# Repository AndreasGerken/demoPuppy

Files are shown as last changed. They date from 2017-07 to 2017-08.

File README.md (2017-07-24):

# Demo Puppy

This is a fork of the demoPuppy which was originally designed by K. Dermitzakis [dermitza](https://github.com/dermitza). The original files are described on his [website](https://dermitza.github.io/demoPuppy/).

## Modified files
New models were added which are compatible with the original models. They include
- Servo holders for cheap Carson CS-3 standard size servos
- Flexible legs which can be printed in one piece with flexible filament. We used [Ninjatek's Ninjaflex](https://ninjatek.com/products/filaments/ninjaflex/).
- A one piece body unit which has the holes to hold a Arduino Mega
- A holder for the IMU "MPU6050" which fits to the one piece body

All included files can be 3D printed. We used an Ultimaker2.

The new models are included in the [V5 pack](packs/puppy_v05_one_part_stl.zip). This configuration is shown in the following image:

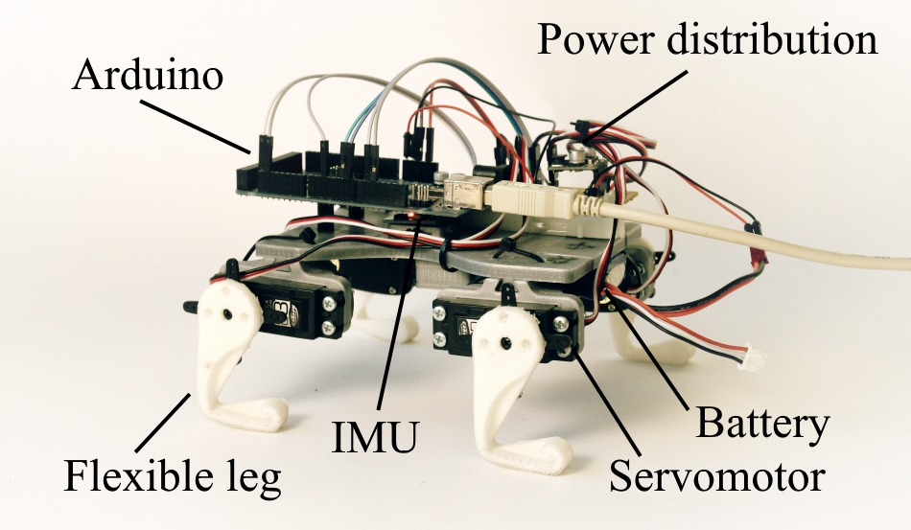
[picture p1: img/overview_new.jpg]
DemoPuppy V5


## Electronics

In our configuration puppy has an IMU and 4 servos for the legs. They can be wired as shown in the following graphic
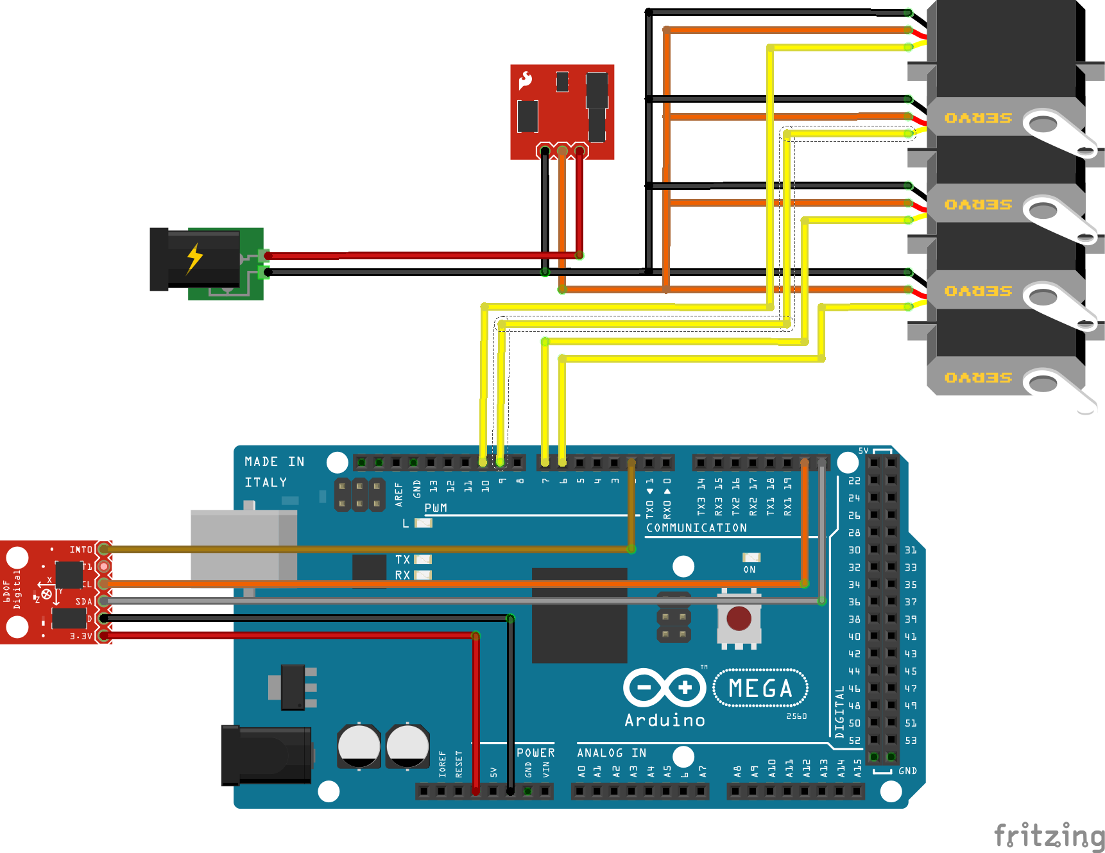
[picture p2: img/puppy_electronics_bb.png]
Wiring


- The red chip on the left is the MPU6050
- the red chip on the top is a voltage regulator. It should fit the requirements of the Servos.
- We use an Arduino Mega

## Arduino program

The arduino program found in arduino/puppy_base is compatible with the wiring shown before.

### Installation
Many parts of the program are identical with the code in the [tinyIMU](https://github.com/AndreasGerken/tinyIMU_arduino) repository.
This repository has a step by step instruction how to install the package which have to be followed to use this package.

### Features
- The program is [ROS](http://www.ros.org/) enabled and can communicate to a ros master via [rosserial](http://wiki.ros.org/rosserial)
- The program reads the IMU measurements with a high frequency (~300Hz), and publishes a smoothed version at around 20Hz with the topic "\tinyIMU" and in the tinyIMU data type to reduce data traffic.
- The program subscribes to motor commands with the topic "\puppyMotor" and gives the corresponding PWM commands to the servos. The value range is between (-32768 and 32768)
- The program runs a diagnostic about the load percentage in it's loop and publishes it with the topic "\timing"

## Additional repositories
 - To transfer the tinyIMU messages to a standard IMU message the package [tinyIMU_relay](https://github.com/superjax/tinyIMU_relay) can be used. The package has a scaling feature to convert the raw values to ROS standard units.
 - The repository [smp_control](https://github.com/AndreasGerken/smp_control) includes configuration files for self exploration of this robot.

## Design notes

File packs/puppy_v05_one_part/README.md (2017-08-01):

# puppy_V05

This version uses the following parts:
- One part body:           With mounting holes for the Arduino Mega
- imu holder:              Holder for the imu MPU 6050
- 4x Servo holder CS-3:    Holders for the Carson CS-3 Servos
- 4x Flexible Legs:        With mounting holes for Carson CS-3 horn

PLA parts
- 0.1 Layer Height
- Support Structure
- PLA (we used Form Futura EasyFillPLA)
- Orient the body to easily remove support
- Aproximately 8.6m Material
- 2 Gradual infill steps (Cura 2.6)
- 750g roll costs 24€ and has 168m ->8.6m = 1,23€
- Shapeways ~75€ incl VAT and shipping
https://rigid.ink/blogs/news/how-many-meters-of-filament-on-a-spool

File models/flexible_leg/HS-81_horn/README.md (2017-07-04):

# Flexible leg for Hitech HS-81 horn

All models in this folder are meant to connect to the horn of the Hitech HS-81 servo. The basic model is the same for V2, V3 and V4 but the parameters are configured.

## Parameter meaning
|Param  |Meaning |
|---|---|
|x |Thight lenght |
|y |Knee thickness |
|z |Lower leg length  |
|alpha  |Knee bend angle |
|a |Foot circle radius|

## Version parameter configurations
|Version|x |y |z |alpha|a  |
|---|----|-----|----|-----|---|
|V2 |35mm|3mm  |25mm|35deg|6mm|
|V3 |38mm|3mm  |23mm|30deg|6mm|
|V4 |35mm|3.5mm|23mm|30deg|6mm|

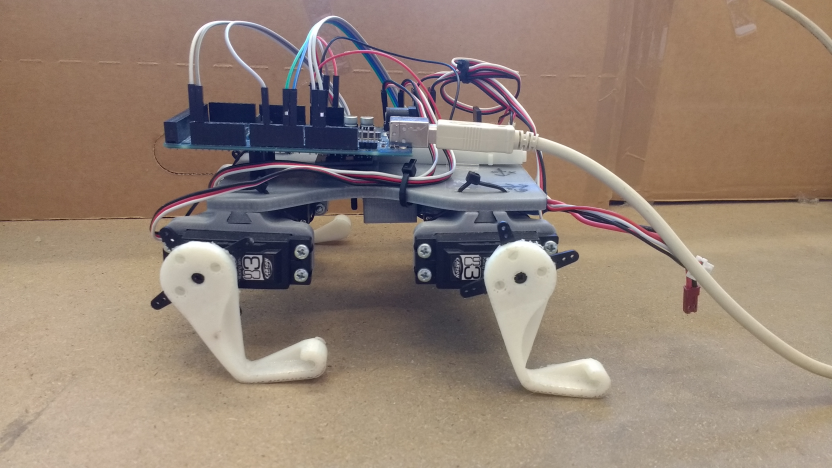
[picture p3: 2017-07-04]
img/demoPuppy_V5.png

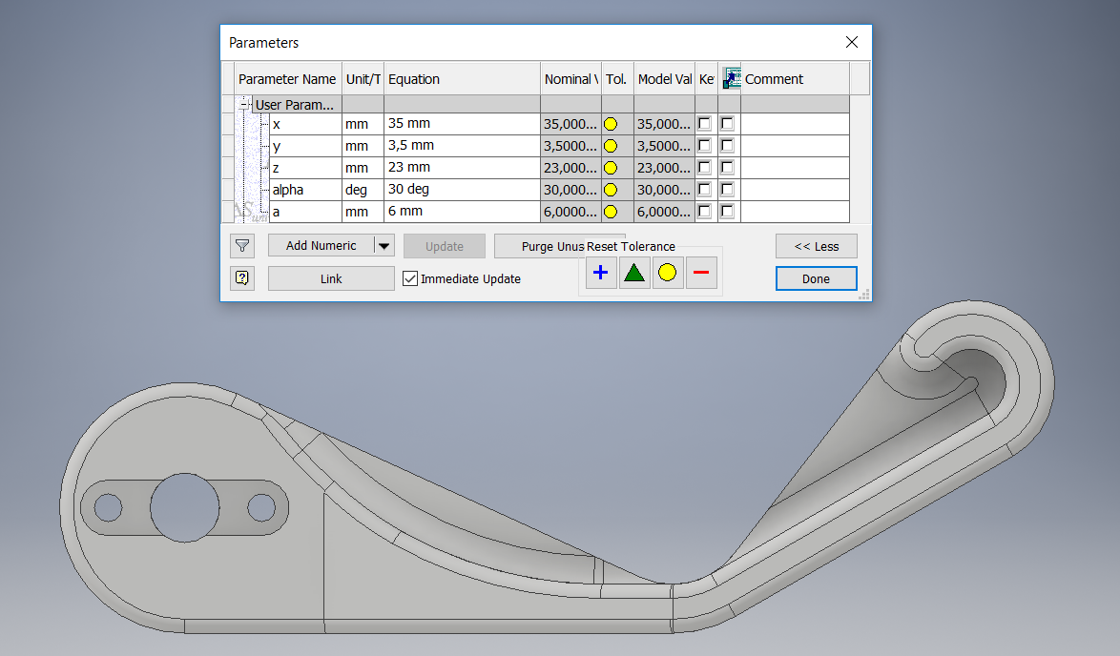
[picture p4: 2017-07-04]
models/flexible_leg/HS-81_horn/V4/flexible_leg_HS-81_V4.PNG

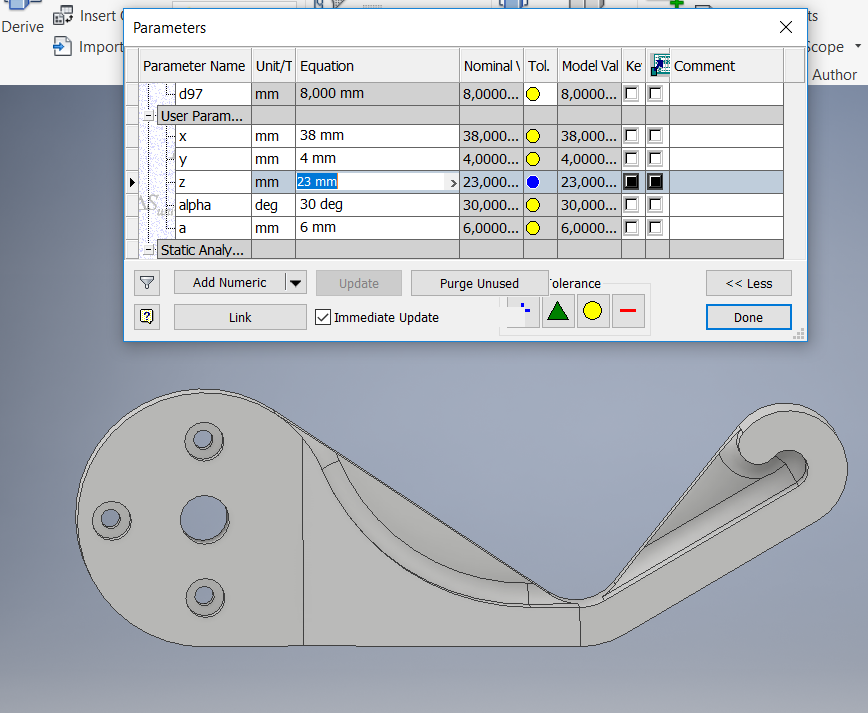
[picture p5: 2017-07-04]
models/flexible_leg/CS-3_horn/flexible_leg_CS-3_V5/flexible_leg_CS-3_V5.PNG

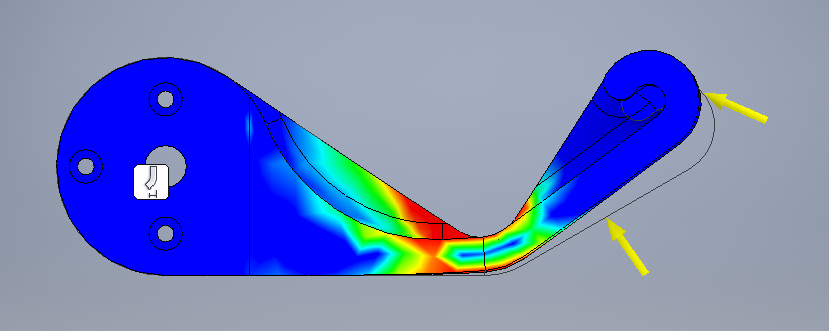
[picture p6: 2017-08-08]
models/flexible_leg/CS-3_horn/flexible_leg_CS-3_V5/flexible_leg_CS-3_V5_stress.png

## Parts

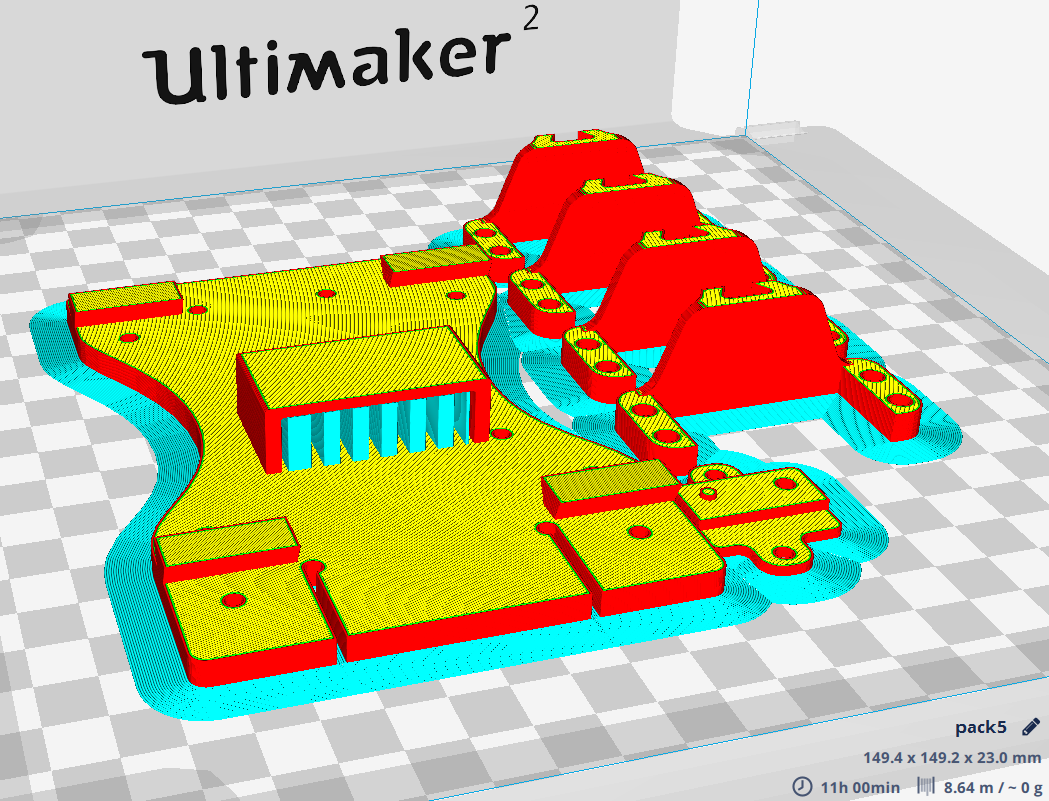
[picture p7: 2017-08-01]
packs/puppy_v05_one_part/cura_pla_parts.PNG

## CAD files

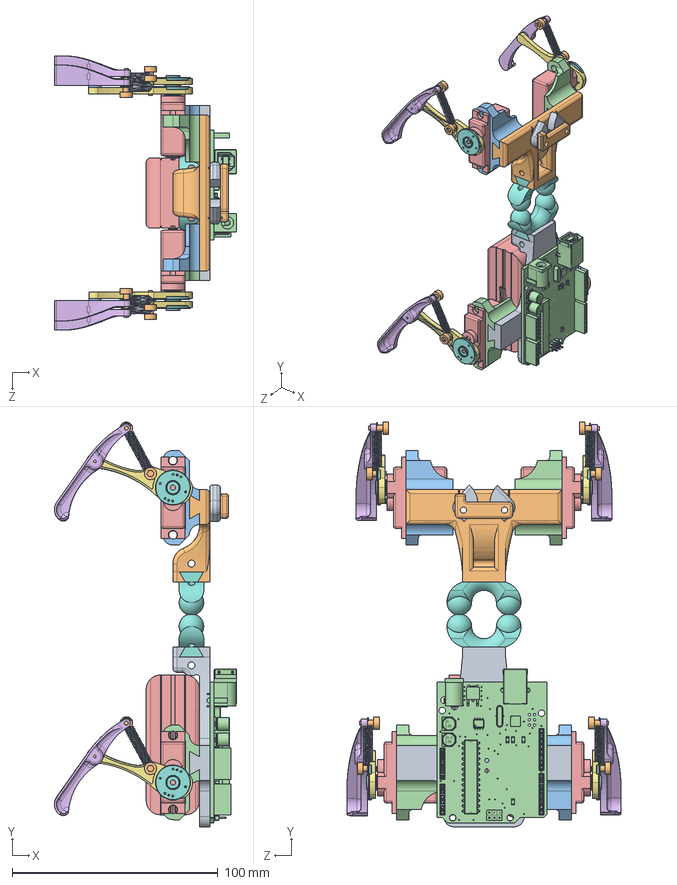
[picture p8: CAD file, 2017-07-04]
models/two_part_body/solidworks/puppy_v04_flexSpine.SLDASM
88.7 x 196.8 x 133.4 mm
body_front
body_rear
HS-81MG_holder_empty x 2
HS-81MG_holder_empty_mirror x 2
HS-81MG x 4
LowerLeg_v2_left x 2
UpperLeg_v2_left x 2
HS-81MG_horn x 4
spring x 4
Schraube x 8
spacerM3_1mm x 4
arduino
1350 mAh 25C LiPo
LowerLeg_v2_right x 2
UpperLeg_v2_right x 2
spine x 2
holder_part x 2
holder_top

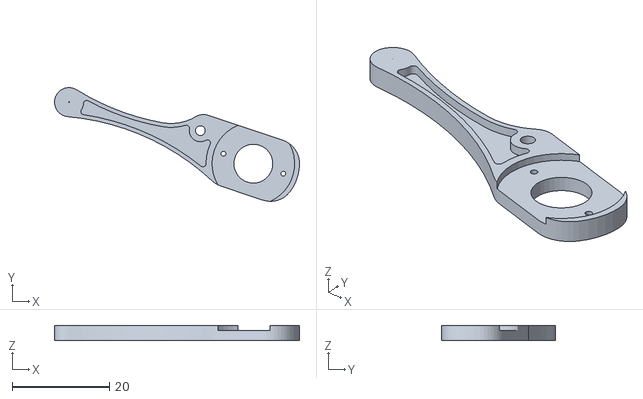
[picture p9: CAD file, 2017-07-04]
models/two_part_leg/stl/puppy_v04_flexSpine - AssemblyLeg_v2_right-1 UpperLeg_v2_right-1.STL
50.4 x 23.4 x 3.00

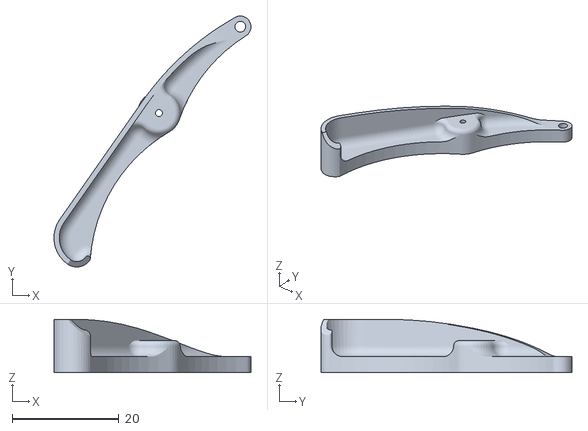
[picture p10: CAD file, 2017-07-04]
models/two_part_leg/stl/puppy_v04_flexSpine - AssemblyLeg_v2_right-1 LowerLeg_v2_right-1.STL
36.9 x 47.0 x 10.00

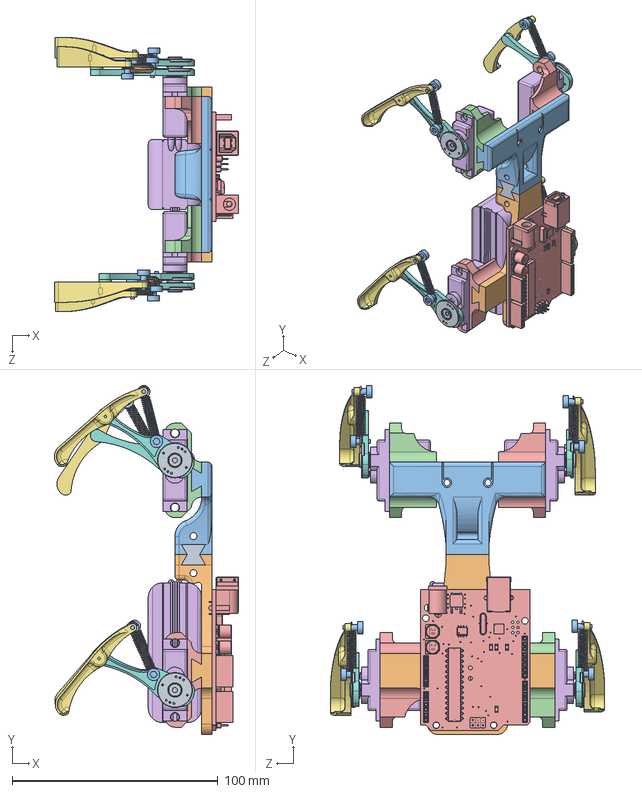
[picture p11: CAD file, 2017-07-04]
models/two_part_body/solidworks/puppy_v04_rigidSpine.SLDASM
89.7 x 169.8 x 133.4 mm
rigid_spine
body_front
body_rear
HS-81MG_holder_empty x 2
HS-81MG_holder_empty_mirror x 2
HS-81MG x 4
LowerLeg_v2_left x 2
UpperLeg_v2_left x 2
HS-81MG_horn x 4
spring x 4
Schraube x 8
spacerM3_1mm x 4
arduino
1350 mAh 25C LiPo
LowerLeg_v2_right x 2
UpperLeg_v2_right x 2

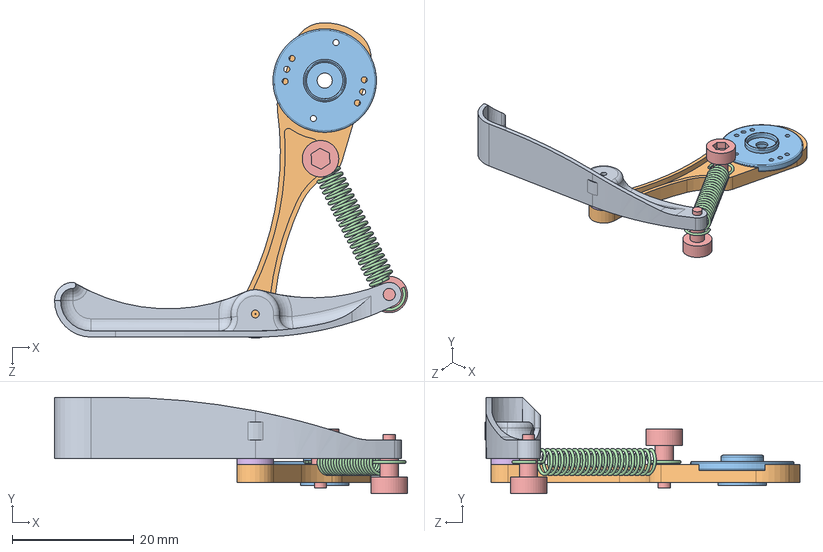
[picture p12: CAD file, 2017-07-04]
models/two_part_leg/solidworks/AssemblyLeg_v2_left.SLDASM
58.0 x 15.8 x 51.8 mm
LowerLeg_v2_left
UpperLeg_v2_left
HS-81MG_horn
spring
Schraube x 2
spacerM3_1mm

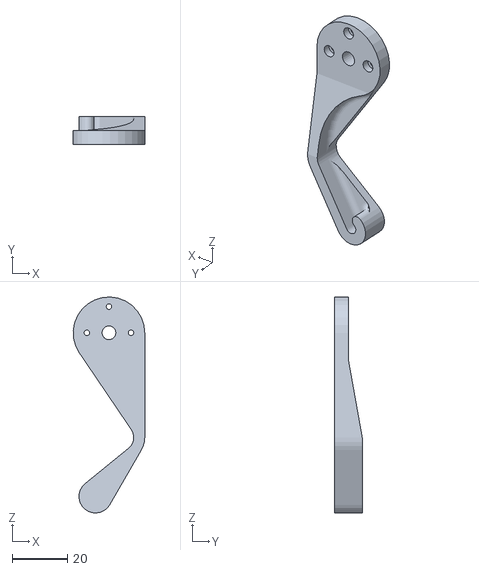
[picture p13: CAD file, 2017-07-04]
models/flexible_leg/CS-3_horn/flexible_leg_CS-3_V5/flexible_leg_CS-3_V5.stl
26.0 x 10.0 x 78.4

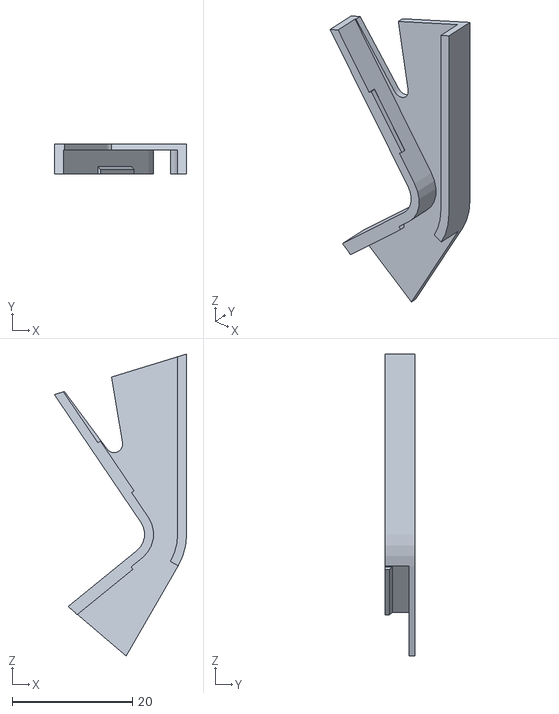
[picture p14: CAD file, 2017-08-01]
models/flexible_leg/CS-3_horn/flexible_leg_CS-3_V5_Armor/flexible_leg_CS-3_V5_Armor.stl
22.0 x 5.00 x 50.2

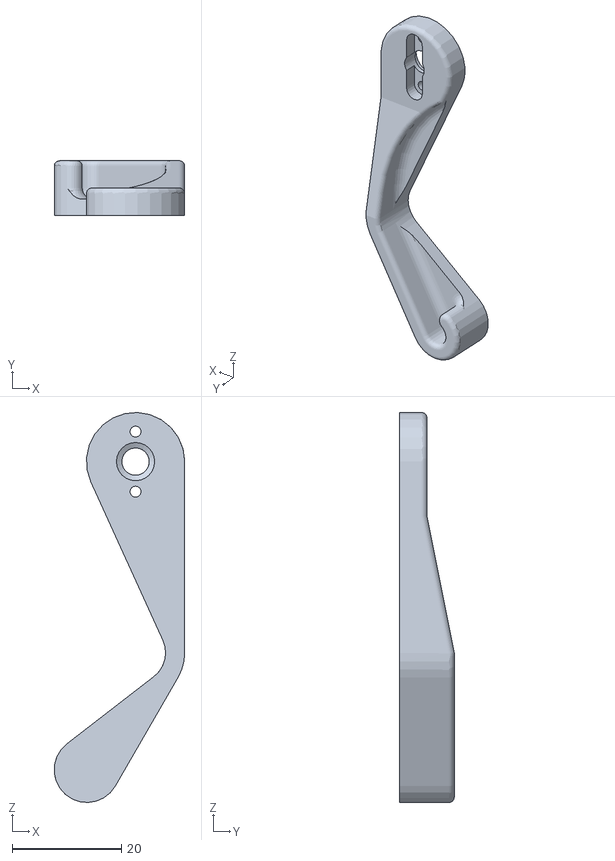
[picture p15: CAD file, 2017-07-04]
models/flexible_leg/HS-81_horn/V4/flexible_leg_HS-81_V4.stl
23.9 x 10.0 x 71.4

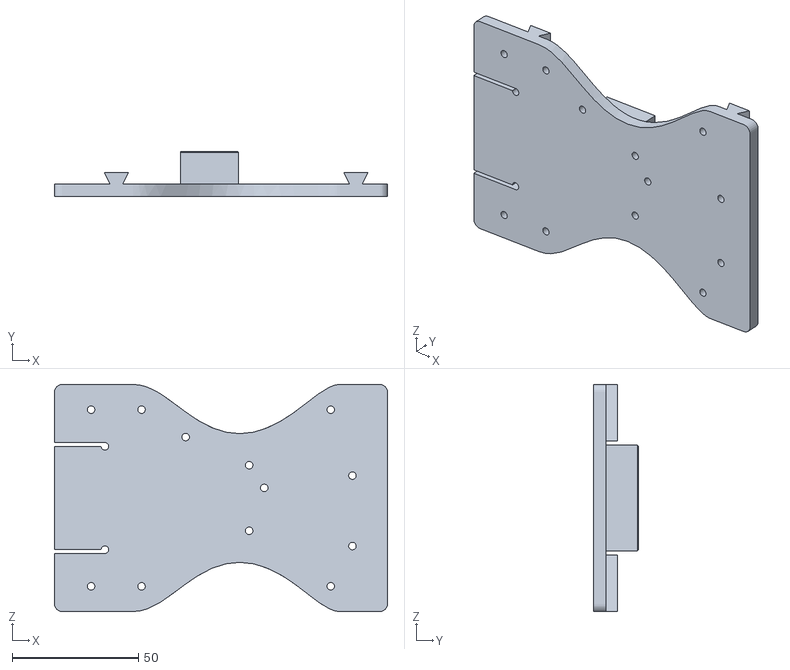
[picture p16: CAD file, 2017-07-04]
models/one_part_body/one_part_body.stl
132.0 x 18.0 x 90.0

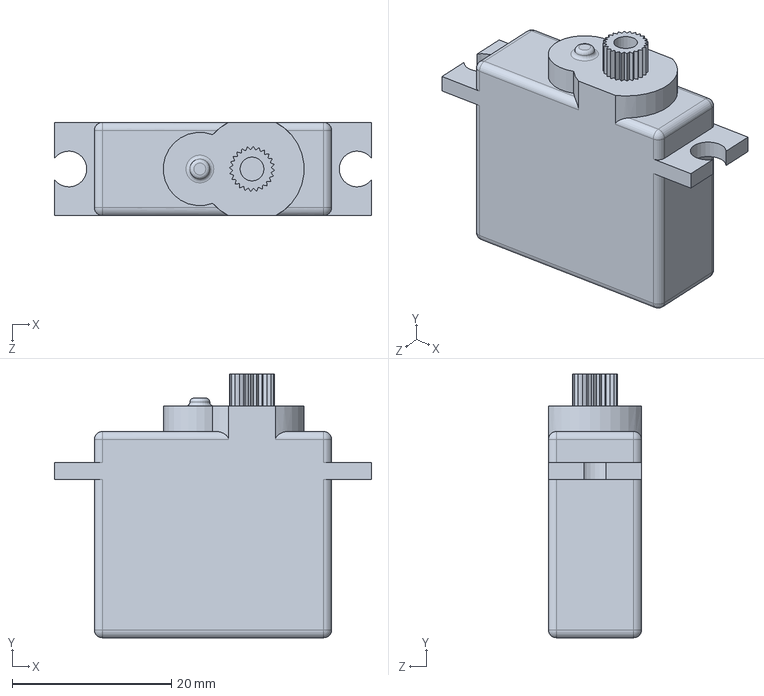
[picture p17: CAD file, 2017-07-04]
models/servo_holder_HS-81/utility/HS-81MG.SLDPRT
39.8 x 33.1 x 11.7 mm

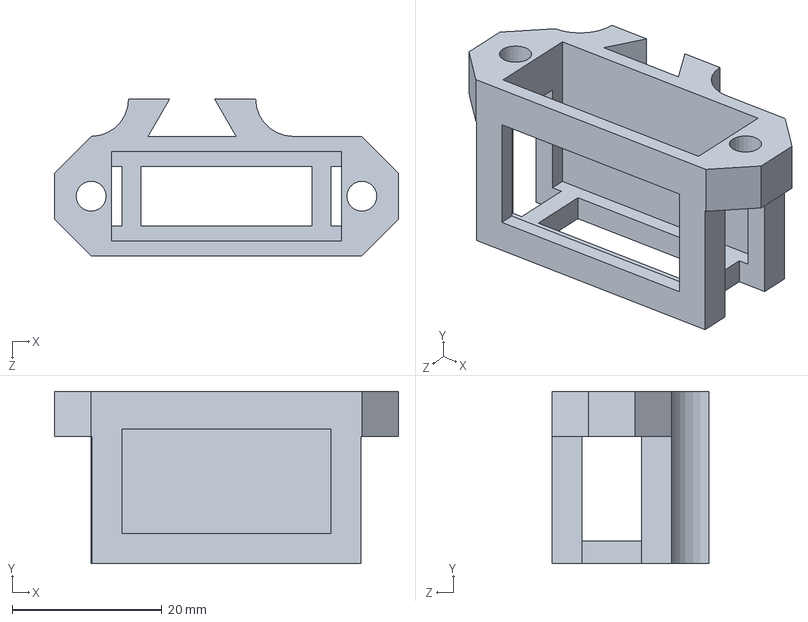
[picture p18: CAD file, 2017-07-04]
models/servo_holder_HS-81/V0/HS-81MG_holder_mirror.SLDPRT
46.0 x 23.0 x 21.0 mm

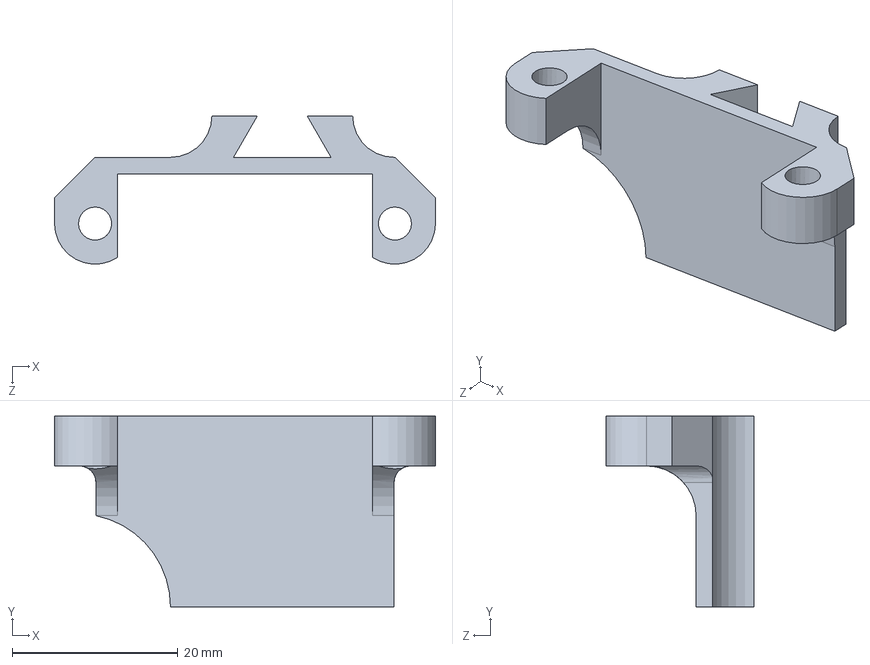
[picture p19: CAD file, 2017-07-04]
models/servo_holder_HS-81/V1_empty/solidworks/HS-81MG_holder_empty.SLDPRT
46.0 x 23.0 x 17.9 mm

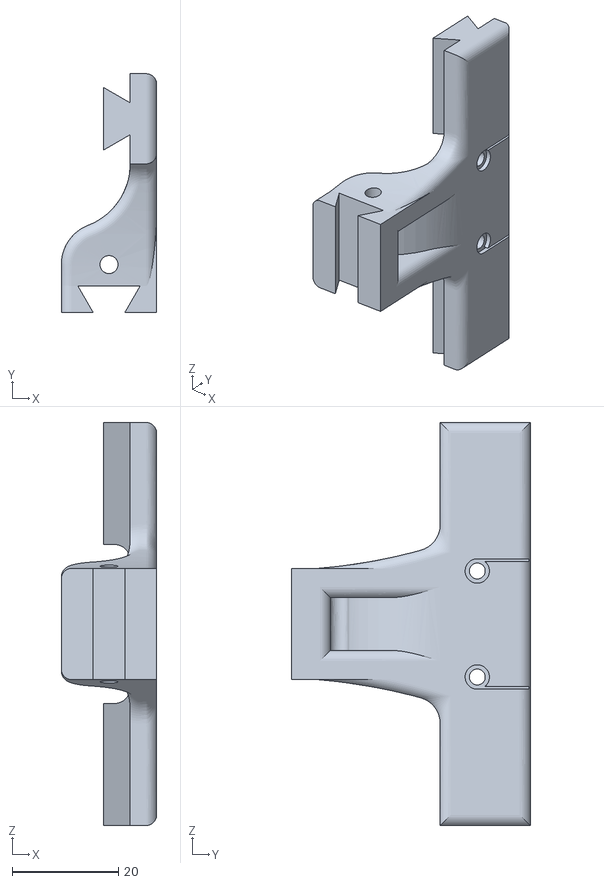
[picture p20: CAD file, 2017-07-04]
models/two_part_body/stl/puppy_v04_flexSpine - body_rear-1.STL
18.0 x 45.0 x 76.0

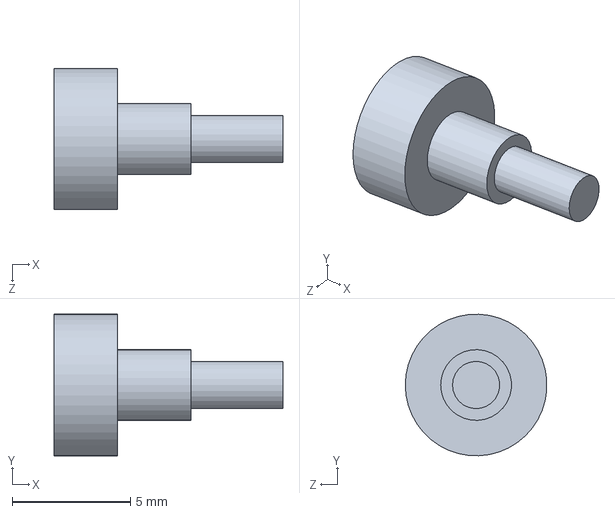
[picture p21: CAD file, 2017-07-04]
models/two_part_leg/solidworks/Schraube.SLDPRT
9.70 x 6.00 x 5.99 mm

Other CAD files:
models/two_part_leg/stl/puppy_v04_flexSpine - AssemblyLeg_v2_left-1 UpperLeg_v2_left-1.STL
models/two_part_leg/stl/puppy_v04_flexSpine - AssemblyLeg_v2_left-1 LowerLeg_v2_left-1.STL
models/two_part_leg/solidworks/AssemblyLeg_v2_right.SLDASM
models/servo_holder_HS-81/V1_empty/stl/puppy_v04_flexSpine - HS-81MG_holder_empty_mirror-1.STL
models/flexible_leg/CS-3_horn/flexible_leg_CS-3_V5/flexible_leg_CS-3_V5.ipt
models/flexible_leg/CS-3_horn/flexible_leg_CS-3_V5_Armor/OldVersions/flexible_leg_CS-3_V5_Armor.0003.ipt
models/flexible_leg/CS-3_horn/flexible_leg_CS-3_V5_Armor/flexible_leg_CS-3_V5_Armor.ipt
models/flexible_leg/HS-81_horn/V2/flexible_leg_HS-81_V2.ipt
models/flexible_leg/HS-81_horn/V2/flexible_leg_HS-81_V2.stl
models/flexible_leg/HS-81_horn/V3/flexible_leg_HS-81_V3.ipt
models/flexible_leg/HS-81_horn/V3/flexible_leg_HS-81_V3.stl
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

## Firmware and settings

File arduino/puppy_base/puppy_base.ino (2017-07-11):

// I2C device class (I2Cdev) demonstration Arduino sketch for MPU6050 class
// 10/7/2011 by Jeff Rowberg <jeff@rowberg.net>
// Updates should (hopefully) always be available at https://github.com/jrowberg/i2cdevlib
//
// Changelog:
//      2013-05-08 - added multiple output formats
//                 - added seamless Fastwire support
//      2011-10-07 - initial release

/* ============================================
I2Cdev device library code is placed under the MIT license
Copyright (c) 2011 Jeff Rowberg

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
TODO: Rewrite

Notes Andreas Gerken:
- The timing message gives a rough idea of the percentage of time, in which the arduino is active.
  On the Arduino Mega 3ms as imu interval led to ~ 35% activity, 2ms led to 80% activity which could possibly disturb the other loops
===============================================
*/

// I2Cdev and MPU6050 must be installed as libraries, or else the .cpp/.h files
// for both classes must be in the include path of your project
#include "I2Cdev.h"
#include "MPU6050.h"
#if I2CDEV_IMPLEMENTATION == I2CDEV_ARDUINO_WIRE
    #include "Wire.h"
#endif

MPU6050 accelgyro;
int16_t ax, ay, az, gx, gy, gz;
double ax_m, ay_m, az_m, gx_m, gy_m, gz_m;
double accel_alpha = 0.15;
double gyro_alpha = 0.15;
//double motor_alpha = 0.1;

#include <ros.h>
#include <ros/time.h>
#include <tiny_msgs/tinyVector.h>
#include <tiny_msgs/tinyIMU.h>
#include <std_msgs/Float32MultiArray.h>
#include <std_msgs/Float32.h>

#include <Servo.h>

// General variables
#define dim_m 4 // Legs
#define dim_s 6 // Gyro acceleration and rotation

//#define servoMin 50
//#define servoMax 130

//#define servoMin 1278 // corresponds to 50 deg
//#define servoMax 1722 // corresponds to 130 deg

#define servoMin 1000 // corresponds to 50 deg
#define servoMax 2000 // corresponds to 130 deg

#define servoRealMin 1000
#define servoRealMax 2000

// Prototypes
void writeServoPosition(int servoIndex, int position);
void receiveMotorCommands( const std_msgs::Float32MultiArray& message);
float mapfloat(long x, long in_min, long in_max, long out_min, long out_max);

ros::NodeHandle  nh;

float servoPos[dim_m] = {90, 90, 90, 90};

tiny_msgs::tinyIMU imu_msg;
std_msgs::Float32 timing_msg;

ros::Publisher imu_pub("tinyImu", &imu_msg);
ros::Publisher timing_pub("timing", &timing_msg);

ros::Subscriber<std_msgs::Float32MultiArray> subscriber("puppyMotor", receiveMotorCommands);

uint32_t seq;
unsigned long currentMillis;

unsigned long publishPrevious = 0;
unsigned long spinPrevious = 0;
unsigned long imuPrevious = 0;
unsigned long timingPrevious = 0;

unsigned long publishInterval = 50;
unsigned long spinInterval = 10;
unsigned long imuInterval = 3;
unsigned long timingInterval = 1000;

unsigned long activeTime = 0;

// Servo variables
int16_t servoPin[dim_m] = {5, 6, 9, 10};
bool servoRevert[dim_m] = {true, false, true, false};
int16_t servoOffset[dim_m] = {0, 0, 0, 0};
Servo   servos[dim_m];


void setup()
{
    // join I2C bus (I2Cdev library doesn't do this automatically)
  #if I2CDEV_IMPLEMENTATION == I2CDEV_ARDUINO_WIRE
      Wire.begin();
  #elif I2CDEV_IMPLEMENTATION == I2CDEV_BUILTIN_FASTWIRE
      Fastwire::setup(400, true);
  #endif
  Serial.begin(9600);
  
  nh.initNode();
  nh.advertise(imu_pub);
  nh.advertise(timing_pub);
  nh.subscribe(subscriber);
  
  nh.loginfo("ROS Setup finished, starting MPU6050");
  
  accelgyro.initialize();

  // set offsets, the values are measured with the calibration script from https://www.i2cdevlib.com/forums/topic/96-arduino-sketch-to-automatically-calculate-mpu6050-offsets/ and are specific to one IMU!!
  accelgyro.setXAccelOffset(-1373);
  accelgyro.setYAccelOffset(-2669);
  accelgyro.setZAccelOffset(1793);
  accelgyro.setXGyroOffset(64);
  accelgyro.setYGyroOffset(10);
  accelgyro.setZGyroOffset(53);

  // MPU 6050 initialization
  nh.loginfo(accelgyro.testConnection() ? "MPU6050 connection successfull" : "MPU6050 connection failed");

  seq = 0;

  // Attach Servos
  for(int i = 0; i < dim_m; i++){
    servos[i].attach(servoPin[i]);
    servos[i].write(servoPos[i]);
  }
}

void loop()
{
  currentMillis = millis();

  // check which case should be executed (important first)
  if(currentMillis - publishPrevious >= publishInterval && nh.connected()){
    /*
     * The smoothed imu values are published
     */

    seq ++;
    imu_msg.header.stamp = nh.now();
    imu_msg.header.frame_id = 0;
    imu_msg.header.seq = seq;
  
    imu_msg.accel.x = (int16_t)ax_m;
    imu_msg.accel.y = (int16_t)ay_m;
    imu_msg.accel.z = (int16_t)az_m;
    imu_msg.gyro.x = (int16_t)gx_m;
    imu_msg.gyro.y = (int16_t)gy_m;
    imu_msg.gyro.z = (int16_t)gz_m;
    
    imu_pub.publish( &imu_msg );

    // accumulate active time
    activeTime += millis() - currentMillis;
    
    publishPrevious = currentMillis;
  }else if(currentMillis - spinPrevious >= spinInterval){
    /*
     * Ros node spinning
     */
    
    nh.spinOnce();

    // accumulate active time
    activeTime += millis() - currentMillis;

    spinPrevious = currentMillis;
  }else if(currentMillis - imuPrevious >= imuInterval && nh.connected()) {
    /*
     * Measure IMU and average
     */

    accelgyro.getMotion6(&ax, &ay, &az, &gx, &gy, &gz);
  
    ax_m = (double)ax * accel_alpha + ax_m * (1-accel_alpha);
    ay_m = (double)ay * accel_alpha + ay_m * (1-accel_alpha);
    az_m = (double)az * accel_alpha + az_m * (1-accel_alpha);
    gx_m = (double)gx * accel_alpha + gx_m * (1-gyro_alpha);
    gy_m = (double)gy * accel_alpha + gy_m * (1-gyro_alpha);
    gz_m = (double)gz * accel_alpha + gz_m * (1-gyro_alpha);

    // accumulate active time
    activeTime += millis() - currentMillis;

    imuPrevious = currentMillis;
  }else if(currentMillis - timingPrevious >= timingInterval && nh.connected()){
    /*
     * Send information about the timing activity in period (0-1)
     */
    timing_msg.data = (float)activeTime /timingInterval;
    timing_pub.publish(&timing_msg);


    // reset active time
    activeTime = 0;
    
    timingPrevious = currentMillis;
  }

}


void writeServoPosition(int servoIndex, int position){
  int realPosition = position + servoOffset[servoIndex];

  if(servoRevert[servoIndex]){
    realPosition = servoRealMax - realPosition + servoRealMin;
  }

  servos[servoIndex].writeMicroseconds(realPosition);
}

float mapfloat(long x, long in_min, long in_max, long out_min, long out_max)
{
 if( x > in_max) x = in_max;
 if (x < in_min) x = in_min;
 return (float)(x - in_min) * (out_max - out_min) / (float)(in_max - in_min) + out_min;
}


void receiveMotorCommands( const std_msgs::Float32MultiArray& message){
  long now = millis();
  // write Servos
  for(int i = 0; i < dim_m; i++){
    servoPos[i] = mapfloat(message.data[i], -32768, 32768, servoMin, servoMax);
    writeServoPosition(i, servoPos[i]);
  }
}

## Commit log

2017-07-04 Moved all files to another folder system
    [AssemblyLeg_v2_left.SLDASM, AssemblyLeg_v2_right.SLDASM, HS-81MG.SLDPRT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]
2017-07-04 Added new models and descriptions for them
    [HS-81MG.SLDPRT, HS-81MG_holder.SLDPRT, HS-81MG_holder_empty.SLDPRT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]
2017-07-11 Added electronics drawing
    [puppy_electronics.fzz]
2017-07-11 Added Arduino code with explanation in README
2017-07-24 Added the launch files for puppy and modified the README
    [puppy_electronics.fzz]
2017-08-01 Fixed some holes on the one part body Added Armor for flexible leg
    [flexible_leg_CS-3_V5_Armor.0003.ipt, flexible_leg_CS-3_V5_Armor.ipt, flexible_leg_CS-3_V5_Armor.stl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]
2017-08-08 Added Armor for the legs, Added Stresstest for CS3 leg
    [flexible_leg_CS-3_V5.ipt, flexible_leg_CS-3_V5.stl]
